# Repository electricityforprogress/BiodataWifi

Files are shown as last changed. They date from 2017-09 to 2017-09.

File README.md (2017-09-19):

# BiodataWifi
Biodata Sonification system using ESP8266 and Adafruit CircuitPlayground Classic
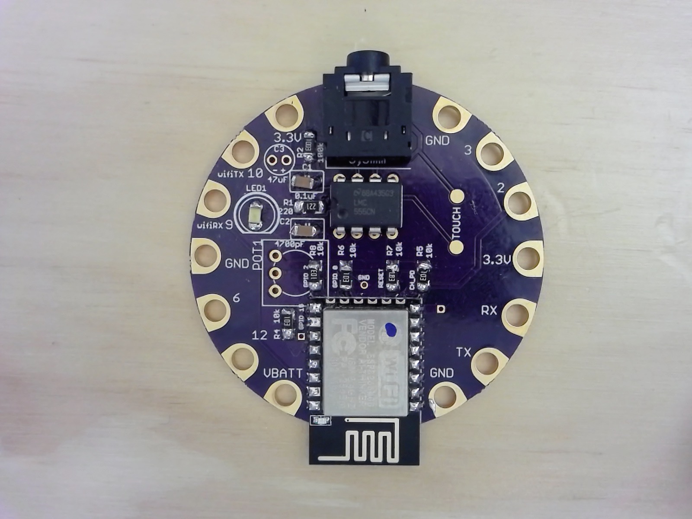
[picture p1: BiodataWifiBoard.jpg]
Biodata Wifi


Biodata Sonification is a process to translate complex real-time sensor data into musical notes and controls, exploring the auditory sensory modality to provide insights into invisible phenomenon. 

Included in this repository are an Arduino Sketch for the Adafruit Circuit Playground 32u4 'Classic' and a Server in Processing3.  Multiple Biodata Nodes can be configured on a Wifi network and their data aggregated by the Server.  Sending MIDI data to software like Ableton Live, dynamic synthesized sounds can be created.

Using the Circuit Playground Switch, Serial data can be output (+) or USB MIDI connectivity (-)
Serial data is represented using the Serial Plotter :
  * Change - Light Blue
  * Threshold - Grey
  * Delta - Magenta
  * Minium - Orange
  * Maximum - Green
  * Standard Deviation - Red
  * Average - Blue
  
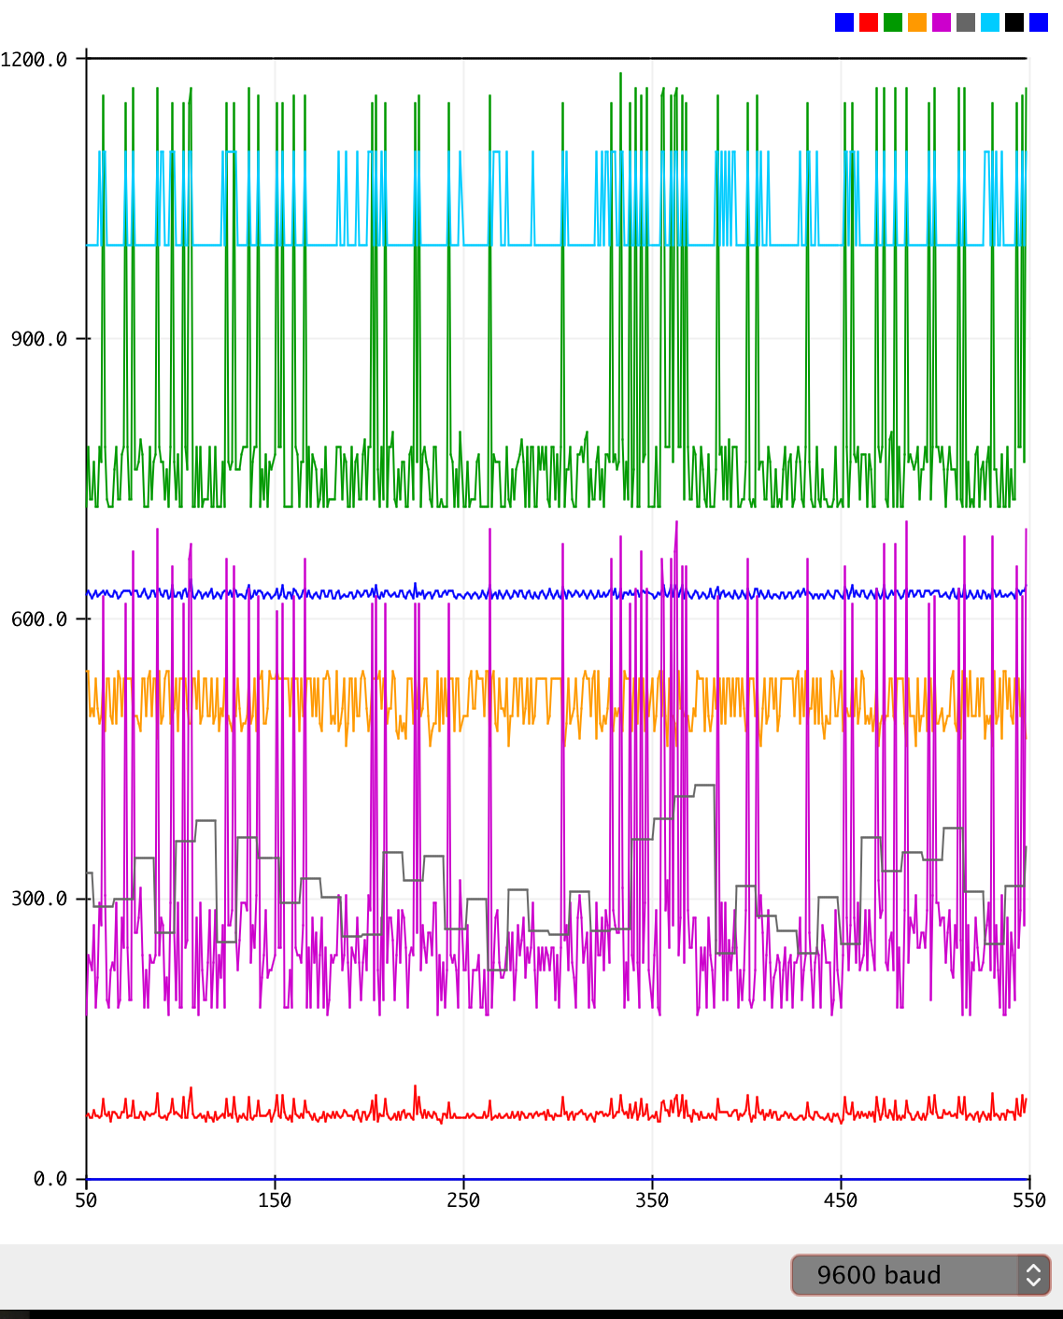
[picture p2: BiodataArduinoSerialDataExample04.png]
Serial Data


3D Printed Enclosure - 
https://www.tinkercad.com/embed/lpzT7Wl8fgM?editbtn=1

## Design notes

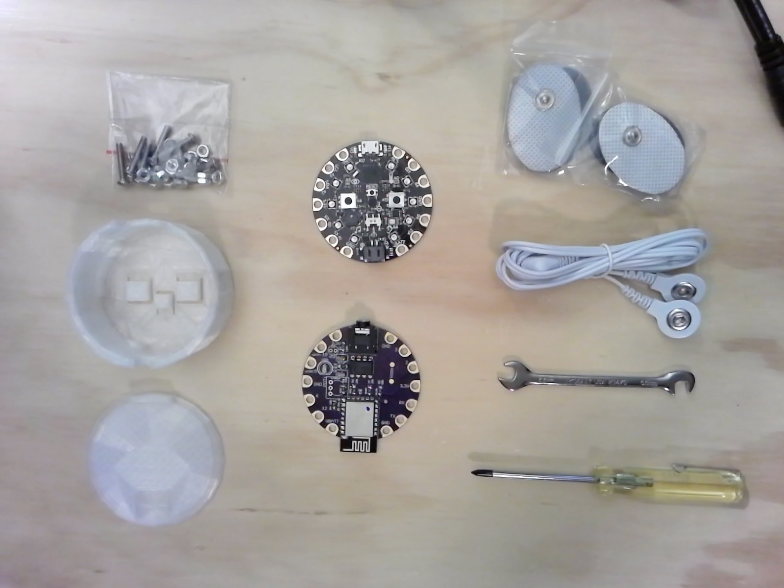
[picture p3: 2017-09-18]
BiodataWifiKit.jpg

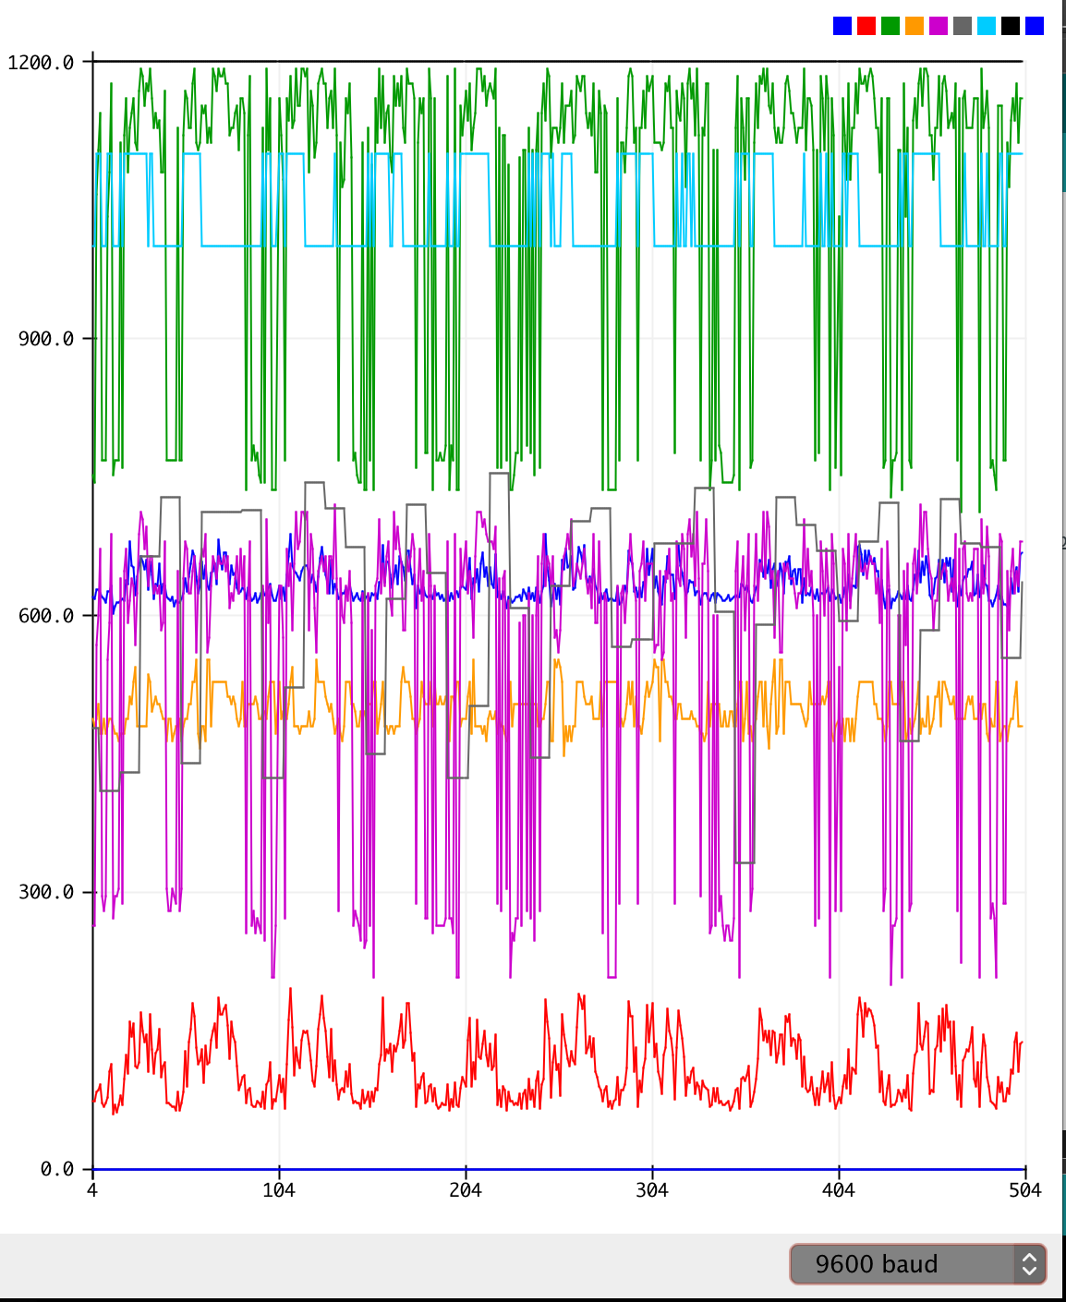
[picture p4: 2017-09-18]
BiodataArduinoSerialDataExample03.png

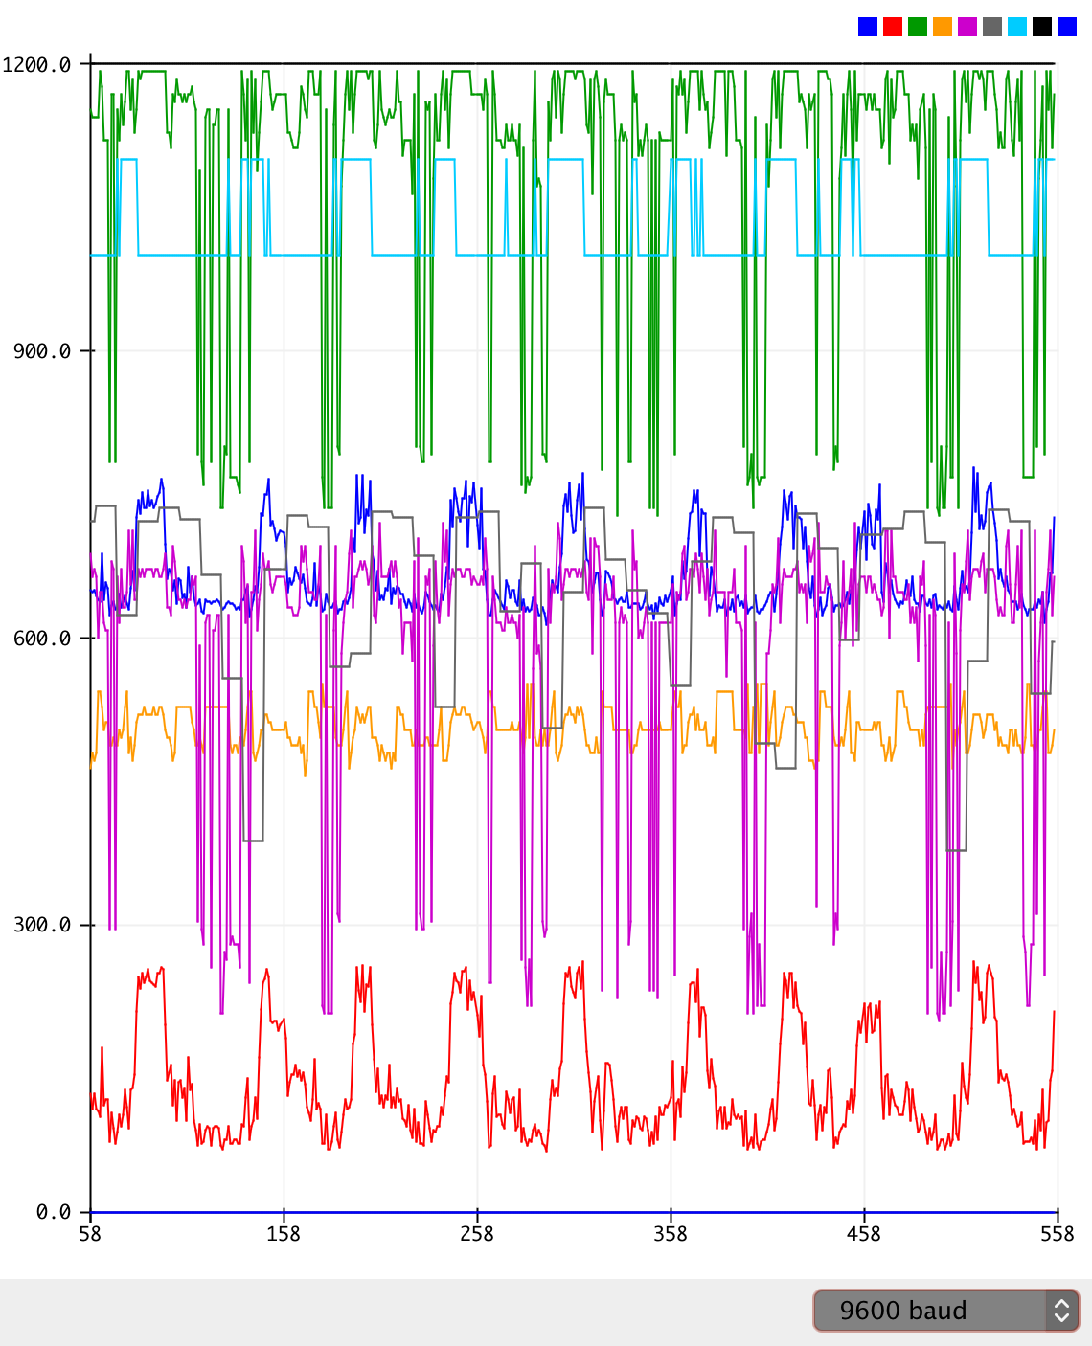
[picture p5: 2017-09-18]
BiodataArduinoSerialDataExample02.png

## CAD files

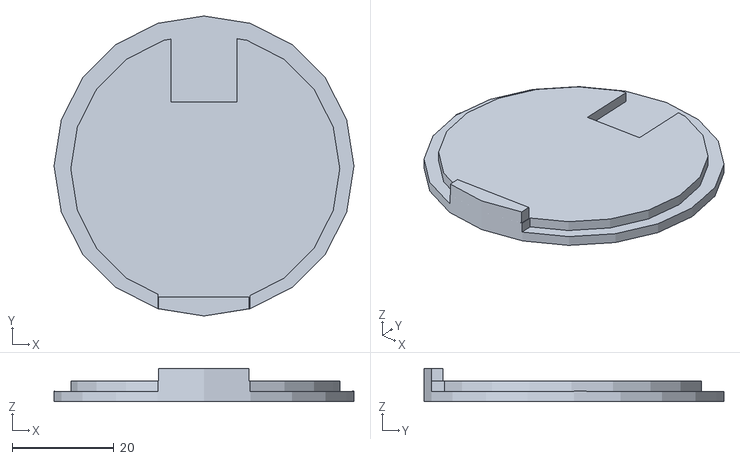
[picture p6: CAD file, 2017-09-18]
Enclosure/CircuitPlayground_Wifi Case_bottom.stl
59.0 x 59.0 x 6.50

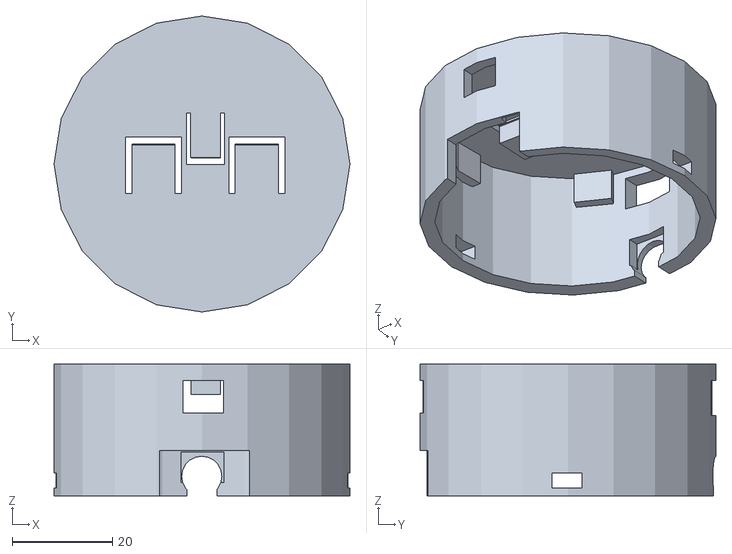
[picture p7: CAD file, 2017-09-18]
Enclosure/CircuitPlayground_Wifi Case_top.stl
59.0 x 59.0 x 26.3

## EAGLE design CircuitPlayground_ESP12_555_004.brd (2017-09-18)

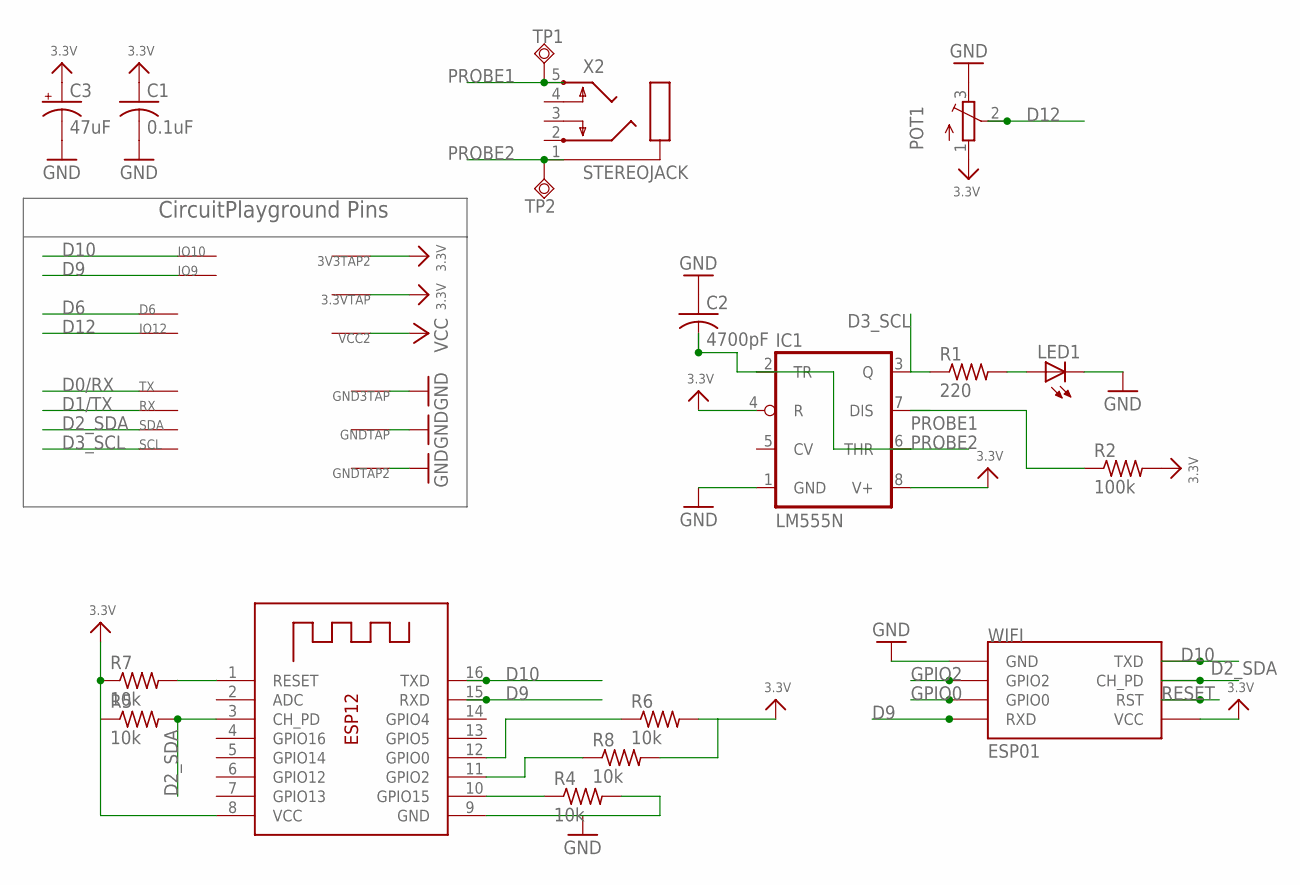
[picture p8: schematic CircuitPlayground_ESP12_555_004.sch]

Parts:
3.3VTAP, 3V3TAP2: SEWTAP-ALLIGATOR; SEWALLI
C1: 0.1uF; C025-030X050
C2: 4700pF; C025-030X050
C3: 47uF; E2-4
D6: SEWTAP-ALLIGATOR; SEWALLI
GND3TAP: SEWTAP-ALLIGATOR; SEWALLI
GNDTAP, GNDTAP2: SEWTAP-ALLIGATOR; SEWALLI
IC1: LM555N; DIL08-ROUND
IO9, IO10, IO12: SEWTAP-ALLIGATOR; SEWALLI
LED1: LED5MM
POT1: TRIMPOT3386; TRIM-3386
R1: 220; R1206
R2: 100k; R1206
R4, R5, R6, R7, R8: 10k; R1206
RX: SEWTAP-ALLIGATOR; SEWALLI
SCL: SEWTAP-ALLIGATOR; SEWALLI
SDA: SEWTAP-ALLIGATOR; SEWALLI
TP1, TP2: TPSQTP20R; TP20R
TX: SEWTAP-ALLIGATOR; SEWALLI
VCC2: SEWTAP-ALLIGATOR; SEWALLI
WIFI: ESP01
X1: ESP-12
X2: STEREOJACK; STX3100

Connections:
3.3V: 3.3VTAP.P$1, 3V3TAP2.P$1, C1.1, C3.+, IC1.4 (R), IC1.8 (V+), POT1.1 (A), R2.2, R5.1, R6.2, R7.1, R8.2, WIFI.VCC, X1.8 (VCC)
D0/RX: TX.P$1
D1/TX: RX.P$1
D2_SDA: R5.2, SDA.P$1, WIFI.CH_PD, X1.3 (CH_PD)
D3_SCL: IC1.3 (Q), R1.1, SCL.P$1
D6: D6.P$1
D9: IO9.P$1, WIFI.RX (RXD), X1.15 (RXD)
D10: IO10.P$1, WIFI.TX (TXD), X1.16 (TXD)
D12: IO12.P$1, POT1.2 (S)
GND: C1.2, C2.1, C3.-, GND3TAP.P$1, GNDTAP.P$1, GNDTAP2.P$1, IC1.1 (GND), LED1.K (C), POT1.3 (E), R4.2, WIFI.GND, X1.9 (GND)
GPIO0: R6.1, WIFI.GPIO0, X1.12 (GPIO0)
GPIO2: R8.1, WIFI.GPIO2, X1.11 (GPIO2)
unnamed: R4.1, X1.10 (GPIO15)
unnamed: LED1.A, R1.2
PROBE1: IC1.7 (DIS), R2.1, TP1.TP, X2.5
PROBE2: C2.2, IC1.2 (TR), IC1.6 (THR), TP2.TP, X2.1
RESET: R7.2, WIFI.RST, X1.1 (RESET)
VCC: VCC2.P$1

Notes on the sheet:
CircuitPlayground Pins

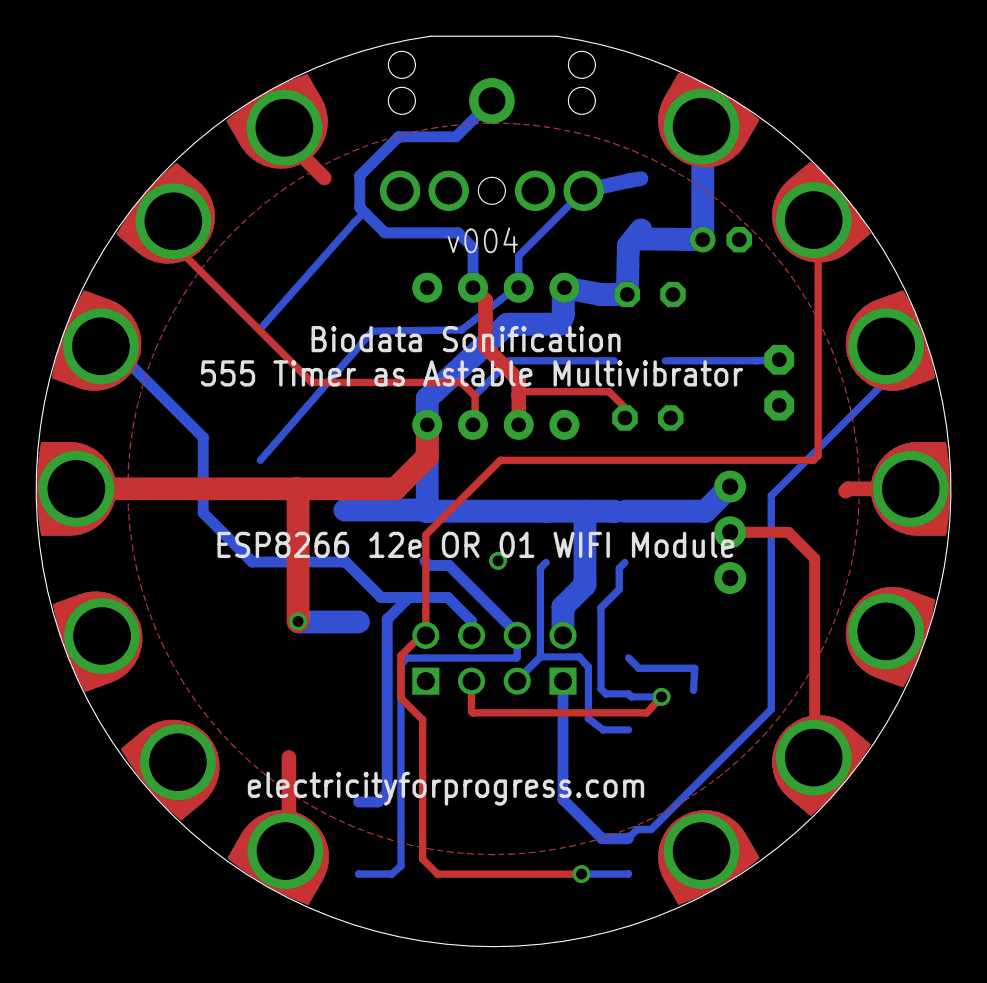
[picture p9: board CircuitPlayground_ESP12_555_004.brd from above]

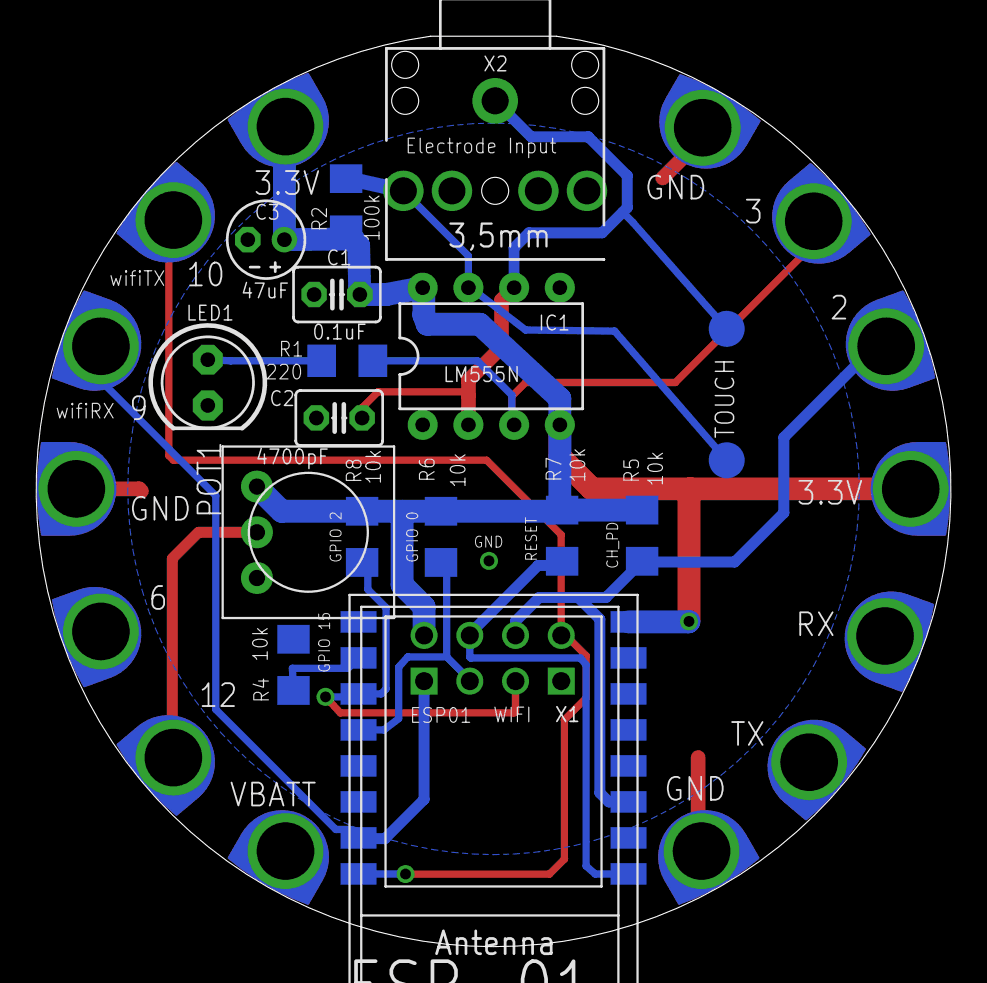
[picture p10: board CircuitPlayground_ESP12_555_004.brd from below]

Board: 2 copper layers, 50.8 x 50.6 mm, 32 parts (18 on the bottom side), 14 nets.

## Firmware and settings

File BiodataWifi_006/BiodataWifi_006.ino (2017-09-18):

/*
 * 1. Read pulse widths from 555 timer, store in array
 * 2. Calculate 'change detection' and note values
 * 3. MIDI output - USB, Serial
 * 4. LED Light Show
 * 5. WIFI Data
 * 6. Modes and Menus
 * 7. Storing parameter settings
 * 
 * 
 */




//#include <Adafruit_CircuitPlayground.h> //super excited!! but can't use it lest modified for wifi
#include <FreqPeriodCounter.h>
#include <SoftwareSerial.h>
#include <ESP8266wifi.h>
#include <Adafruit_NeoPixel.h>
#include <MIDIUSB.h>


#define esp8266_reset_pin 2 // Connect this pin to CH_PD on the esp8266, not reset. (let reset be unconnected)

#define SERVER_IP  "192.168.1.157"   //3"  //"10.0.1.2" //
#define SERVER_PORT "1234"
#define SSID "OxfordEast" ////"touch" //
#define PASSWORD "oxfordeast" ////"password123" //

SoftwareSerial ESPSerial(10,9); //talk to the ESP 

//*******************
int nodeID = 2; //Identification of node

//*******************

//Tone note;
int speakerPin = 5;
byte speakerSound = 0; //toggle onboard speaker music
bool toneToggle = false; //speaker on off toggle
long toneMicros = 0;
long currentMicros = 0; //keep time for speaker



int serverConnected = 0; //wifi status toggle
int usbMIDI = 0; // toggle MIDI through USB
int serialBiodata = 1; //output serial data for arduino logger
byte debugSerial=0; //toggle serial terminal debugging

byte inputPin = 3; ///555 timer input, Pin 3 - SCL INT0
int reading = 0;
int prevReading = 0;

const int deltaCount = 10;
int deltaAverage[deltaCount]; //sample to identify average delta fluctutation
int deltaAvg = 0;
float threshold = 0.1; 
float thresholdMin = 0.03;
float thresholdMax = 0.85;
float thresholdAmount = 0.013;
int deltaIndex = 0;


const int LED_NUM = 10;
int ledPin = 17; // first neopixel on Circuit Playground
//manage our own neopixels, until i can get the playground.begin() to work with wifi
Adafruit_NeoPixel pixels = Adafruit_NeoPixel(LED_NUM, ledPin, NEO_GRB + NEO_KHZ800);
int ledPixels[LED_NUM] = {0,1,2,3,4,5,6,7,8,9};
int maxBright = 45; //brightness level to apply between 0 and 255
int fadeRate = 10; //fade for pulse?


int potPin = 11; //pin 12 in test
float tempValue = 0;
int lightValue = 0; 
int change = 0; 
int wifi_started = 0;

long currentMillis = 0;
long prevMillis = 0;


FreqPeriodCounter freqPeriodCounter(inputPin, micros, 0);
//ESP8266wifi wifi(ESPSerial, ESPSerial, esp8266_reset_pin,Serial);
ESP8266wifi wifi(ESPSerial, ESPSerial, esp8266_reset_pin); //no serial echo

const int sampleSize = 100; //number of value 
int sampleIndex = 0;
int pulseInput[sampleSize];

//menu modes navigated by buttons and LEDs
int mode = 0; //0 normal, 1 wifi signal meter

String inputString;
byte stringComplete=0;

const int polyphony = 10; //max notes to be managed locally at same time (usb MIDI, light show)
//additional notes will be ignored (unlimited poly may be sent via wifi)

typedef struct _MIDImessage { //build structure for Note and Control MIDImessages
  unsigned int type;
  int channel;
  int value;
  int velocity;
  long duration;
  long timeStamp;
} 
MIDImessage;
MIDImessage noteArray[polyphony]; //manage MIDImessage data as an array with size polyphony


void ledPulse(int led = 0, int pulses = 0, int r = 0, int g =0 , int b = 0, long duration = 0) {
  //fade specified LED the specified number of times over the duration in the color
  for(byte k=0;k<pulses;k++){
    for(byte i=0;i<maxBright;i++){ //fade, perhaps?
      setColor(led,r,g,b,i);
      delay(duration); //wait for next cycle
    }
  }
}



void setup() {

  randomSeed(A0); 
  
  Serial.begin(9600); //usb debugging
    
  ESPSerial.begin(9600); //wifi serial

  ledSetup(); //test and setup the LEDs

  wifiSetup(); //initialize wifi settings and connect to server

  pinMode(4, INPUT_PULLUP); //left button
  pinMode(19, INPUT_PULLUP); //right button
  pinMode(21, INPUT_PULLUP); //slide switch
  
  pinMode(speakerPin, OUTPUT); //speaker

  //initialize noteArray objects
  for(byte i=0;i<polyphony;i++) { //iterate through notes
      noteArray[i].type = 0; //note type
      noteArray[i].channel = 0;
      noteArray[i].value = 0;
      noteArray[i].velocity = 0;
      noteArray[i].duration = 0;
      noteArray[i].timeStamp = 0;
   }
  
  
}

void loop() {

  currentMillis = millis();
//    currentMillis = currentMicros/1000;
  currentMicros = micros();

  checkButtons();
  
  if(mode == 0) checkInput(); //normal running mode
  if(mode == 1) { //wifi signal meter
    if(currentMillis - prevMillis > 5000){
      prevMillis = currentMillis;  
      //environmentSensors();
      measureSignal(); //wifi signal meter
    }
  }
  
  checkNote(); //update notes, turn on or off accordingly
  if(speakerSound) checkTone();
  

}

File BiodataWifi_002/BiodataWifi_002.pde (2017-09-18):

// Creates a server that prints new client's IP addresses. 
import themidibus.*; 
import processing.net.*;
import java.util.*;

MidiBus midi; 

int midiOn = 1; //toggle MIDI output 
boolean explicitDebug = true; //toggle explicit debugging

int nodeCount = 10;

int BUFFER = 5000;// 20000; //an attempt at buffering and scheduling the inbound MIDI notes so nodes are self synched

int rateFast = 1; //fast rate, smoothing transition values for 'control' message
int rateSlow = 3; //default rate
int midiAmt = 7; // additive cc modifier, makes the cc fast and jumpy or slow and smooth

String nodeError = "Node: --- ";
String messageError = "Message: --- ";
String insplitError = "inSplit: --- ";
long errorMillis = 0;

int port = 1234;   
Server myServer;     
Client c;

long currentMillis = 0;
long prevMillis = 0;

int polyphony = 100; //maximum number of notes to generate and track from inbound node data

public class node {
 public int nodeID;
 public long timingOffset; //synchronize inbound messages, every day i'm buffering
 public int ipAddress;
 public int[] note = new int[polyphony];  
 public int[] channel = new int[polyphony];
 public int[] velocity = new int[polyphony];
 public long[] duration = new long[polyphony]; //note length or control rate
 public long[] eventTime = new long[polyphony]; //used to sync if buffering multiple nodes  
 public int[] isPlaying = new int[polyphony]; //track notes for buffering
 public float temperature; // Temperature
 public int lightSensor; // 0 - 1023 ~1500 Lux
 
 
  node() {
   nodeID = 0;
   temperature = 0;
   lightSensor = 0;
   timingOffset = 0;
   ipAddress = 0;
   for(byte i=0;i<note.length;i++) note[i] = 0;
   for(byte i=0;i<channel.length;i++) channel[i] = 0;
   for(byte i=0;i<velocity.length;i++) velocity[i] = 0;
   for(byte i=0;i<duration.length;i++) duration[i] = 0;
   for(byte i=0;i<eventTime.length;i++) eventTime[i] = 0;
   for(byte i=0;i<isPlaying.length;i++) isPlaying[i] = 0;
  }
  
}

node nodes[] = new node[nodeCount]; //array of node objects which we will be tracking locally

String input;


void setup() {
  size(120,100,P2D);
  frameRate(20);

  for(int i=0;i<nodeCount;i++) { nodes[i] = new node(); } //initialize those nodes!

  MidiBus.list();
  midi = new MidiBus(this, -1, "IAC Bus 1");
  //midi = new MidiBus(this, -1, "Test");
  
  for(byte i=0;i<nodeCount;i++) nodes[i].nodeID = i+1; //setup node array

  myServer = new Server(this, port); // Starts a server on port 1234
  print("Server is live at ... "); println(Server.ip());
  
}

void draw() {
  
  currentMillis = millis(); //manage global timeclock, easily identify actions in current cycle
  
  readInputs();  //read from clients and parse out their message, updating objects
  
  //implement a rolling buffer in order to 're synch' the data streams of each node, timing is everything!
  
  checkMIDI(); //read current time and objects and update MIDI output 
  
  //clearErrors(); //clear error log with time

}

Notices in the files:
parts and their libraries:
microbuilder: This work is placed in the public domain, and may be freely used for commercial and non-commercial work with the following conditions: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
